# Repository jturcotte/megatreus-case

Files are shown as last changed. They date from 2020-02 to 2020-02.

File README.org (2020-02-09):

* Megatreus Keyboard

The Megatreus is a wireless hand-wired mechanical keyboard based
on the [[https://github.com/technomancy/atreus][Atreus keyboard]].
The layout is customized to use Ergodox keycaps, have a 2u spacebar
and an arrow key cluster.

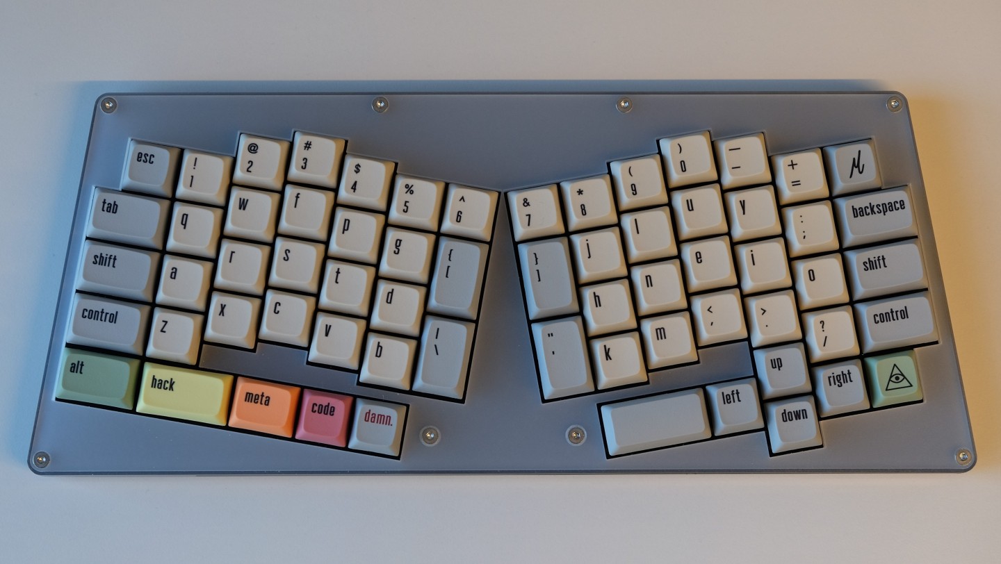
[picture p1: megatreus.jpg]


It uses an [[https://www.adafruit.com/product/4062][Adafruit Feather nRF52840 Express]]
microcontroller as its brain and is using the
[[https://github.com/jturcotte/megatreus-firmware][BlueMicro Firmware]]
to drive it.

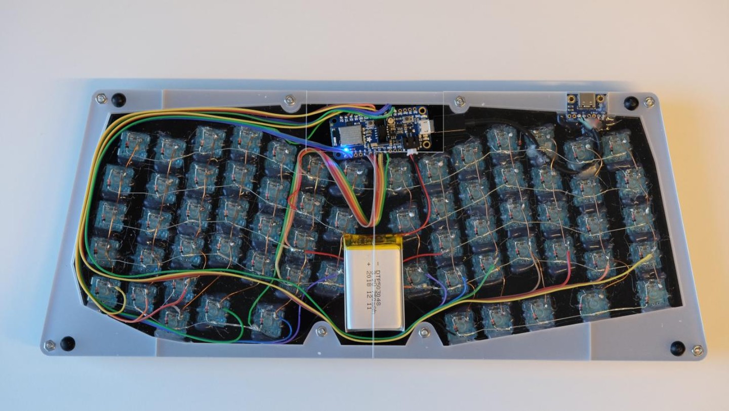
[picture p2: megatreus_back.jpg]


** License

Copyright © 2014-2018 Phil Hagelberg and contributors

Released under the [[https://www.gnu.org/licenses/gpl.html][GNU GPL version 3]]

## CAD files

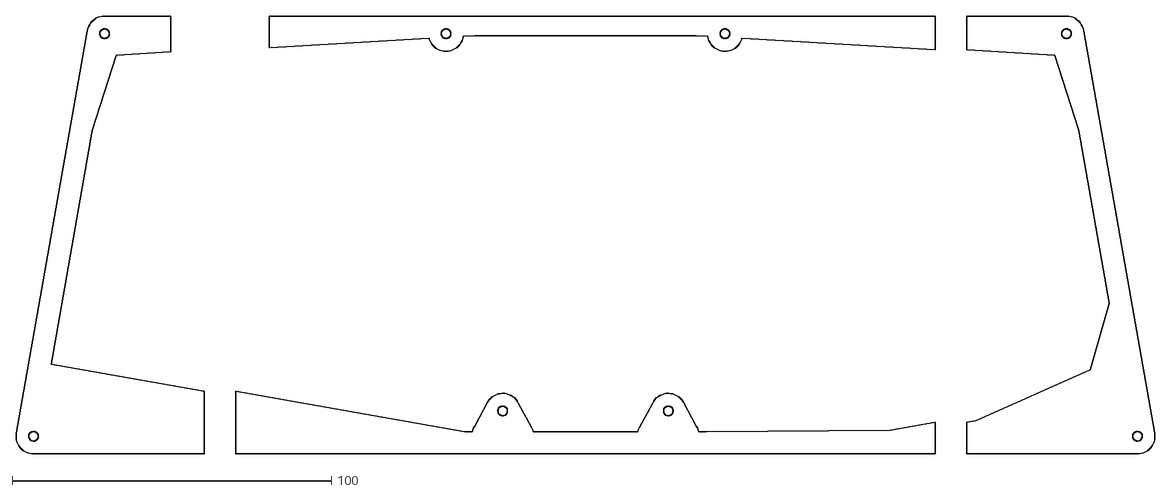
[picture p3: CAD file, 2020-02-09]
case/dxf/spacer.dxf
356.8 x 137.1

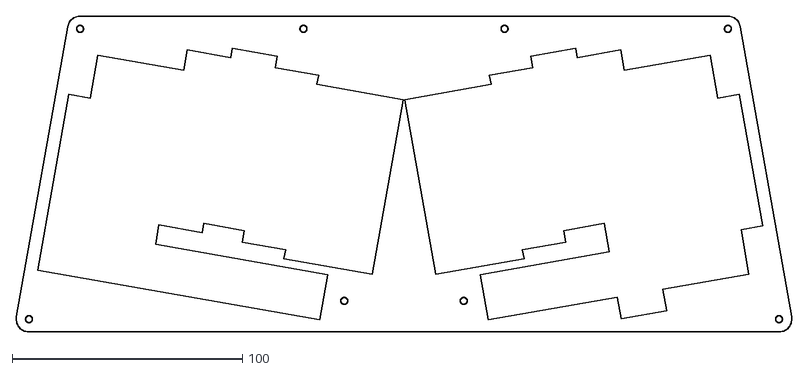
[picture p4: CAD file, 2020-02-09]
case/dxf/top_plate.dxf
336.8 x 137.1

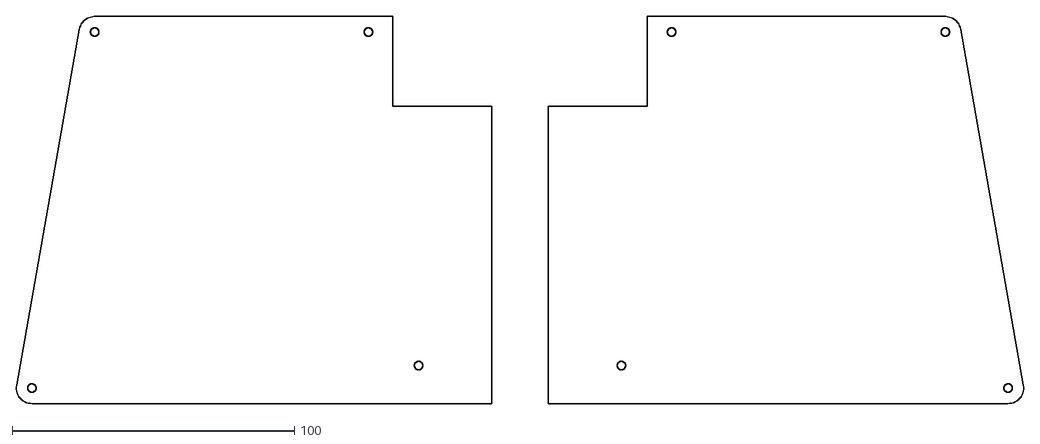
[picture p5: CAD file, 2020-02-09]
case/dxf/bottom_plate.dxf
356.8 x 137.1

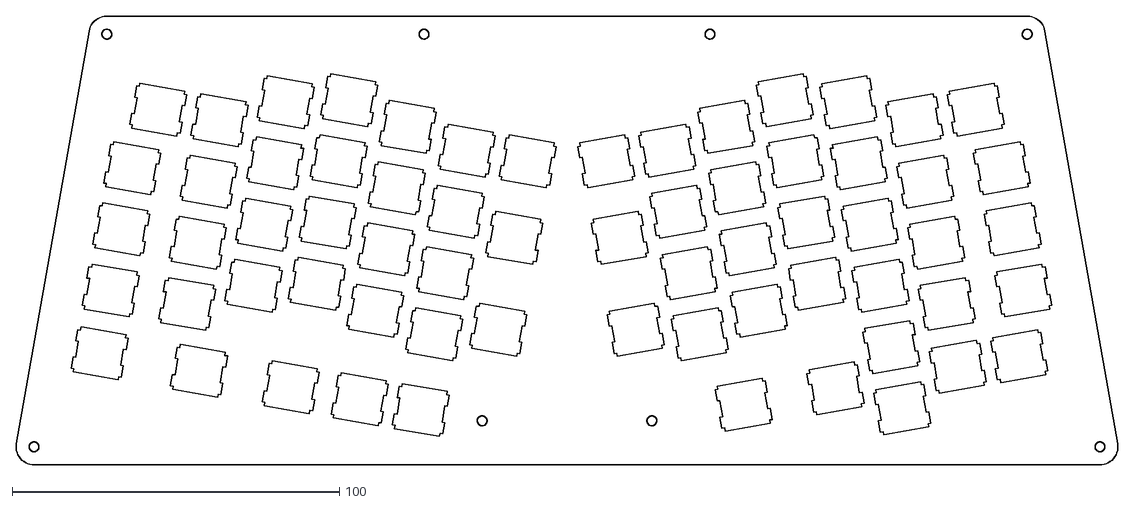
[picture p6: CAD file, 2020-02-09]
case/dxf/switch_plate.dxf
336.8 x 137.1

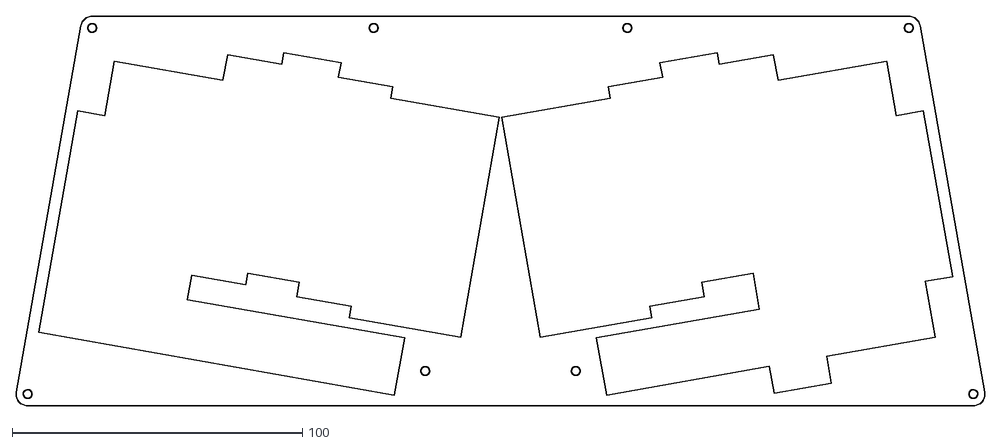
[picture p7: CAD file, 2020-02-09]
case/dxf/top_top_plate.dxf
333.8 x 134.1

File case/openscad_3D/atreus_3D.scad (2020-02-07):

// -*- mode: c -*-
/* All distances are in mm. */

/* set output quality */
$fn = 50;

/* Distance between key centers. */
column_spacing   = 19;
row_spacing      = column_spacing;

/* This number should exceed row_spacing and column_spacing. The
 default gives a 1mm = (20mm - 19mm) gap between keycaps and cuts in
 the top plate.*/
key_hole_size = 20;

/* rotation angle; the angle between the halves is twice this
   number */
angle = 10;

top_most_plate_bezel = 1.5;
/* The radius of screw holes. Holes will be slightly bigger due
   to the cut width. */
screw_hole_radius = 1.5;
/* Each screw hole is a hole in a "washer". How big these "washers"
   should be depends on the material used: this parameter and the
   `switch_hole_size` determine the spacer wall thickness. */
washer_radius     = screw_hole_radius * 2 + top_most_plate_bezel + 1;

/* Distance between halves. */
hand_separation        = 23;

/* The approximate size of switch holes. Used to determine how
   thick walls can be, i.e. how much room around each switch hole to
   leave. See spacer(). */
switch_hole_size = 14;

/* Sets whether the case should use notched holes. As far as I can
   tell these notches are not all that useful... */
use_notched_holes = true;

/* Number of rows and columns in the matrix. You need to update
   staggering_offsets if you change n_cols. */
n_rows = 5;
n_cols = 6;

/* Number of thumb keys (per hand), try 1 or 2. */
n_thumb_keys = 1;

/* The width of the USB cable hole in the spacer. */
cable_hole_width = 21;

/* Vertical column staggering offsets. The first element should
   be zero. */
staggering_offsets = [0, 4, 9, 5, -4, -4];
thumb_keys_y = staggering_offsets[3] - 0.5*column_spacing;

/* Whether or not to split the spacer into quarters. */
quarter_spacer = false;

/* Where the top/bottom split of a quartered spacer will be. */
cable_hole_offset = -120;

module rz(angle, center=undef) {
  /* Rotate children `angle` degrees around `center`. */
  translate(center) {
    rotate(angle) {
      translate(-center) {
        for (i=[0:$children-1])
          children(i);
      }
    }
  }
}

module switch_hole(position, notches=use_notched_holes) {
  /* Cherry MX switch hole with the center at `position`. Sizes come
     from the ErgoDox design. */
  hole_size    = 13.97;
  notch_width  = 3.5001;
  notch_offset = 4.2545;
  notch_depth  = 0.8128;
  translate(position) {
    union() {
        translate([0,0,-1])
      cube([hole_size, hole_size,50], center=true);
      if (notches == true) {
        translate([0, notch_offset,-1]) {
          cube([hole_size+2*notch_depth, notch_width,50], center=true);
        }
        translate([0, -notch_offset,-1]) {
          cube([hole_size+2*notch_depth, notch_width,50], center=true);
        }
      }
    }
  }
};

module keycap_hole(position, size=key_hole_size, ratio = [1, 1]) {
  /* Create a hole for a regular key. */
  translate(position) {
    w = size + column_spacing * (ratio[0] - 1);
    h = size + column_spacing * (ratio[1] - 1);
    cube([w, h, 50], center=true);
  }
}

module key(position, switch_holes, key_size=key_hole_size, ratio = [1, 1]) {
  if (switch_holes == true) {
    switch_hole(position);
  } else {
    keycap_hole(position, key_size, ratio);
  }
}

module regular_key (position, switch_holes, key_size=key_hole_size) {
  key(position, switch_holes, key_size);
}

module thumb_key (position, switch_holes, key_size=key_hole_size) {
  key(position, switch_holes, key_size, [1, 1.5]);
}

module space_bar (position, switch_holes, key_size=key_hole_size) {
  key(position, switch_holes, key_size, [2, 1]);
}

module outside_key (position, switch_holes, key_size=key_hole_size) {
  key(position, switch_holes, key_size, [1.5, 1]);
}

module column (bottom_position, switch_holes, key_size=key_hole_size, n_rows_adj=0) {
  /* Create a column of keys. */
  translate(bottom_position) {
    for (i = [0:(n_rows+n_rows_adj-1)]) {
      regular_key([0, i*column_spacing,-1], switch_holes, key_size);
    }
  }
}

module rotate_half() {
  /* Rotate the right half of the keys around the top left corner of
     the thumb key. Assumes that the thumb key is a 1x1.5 key and that
     it is shifted 0.5*column_spacing up relative to the nearest column. */
  rotation_y_offset = 1.75 * column_spacing;
  for (i=[0:$children-1]) {
    rz(angle, [hand_separation, rotation_y_offset]) {
      children(i);
    }
  }
}

module add_hand_separation() {
  /* Shift everything right to get desired hand separation. */
  for (i=[0:$children-1]) {
    translate([0.5*hand_separation, /* we get back the full separation
                                       because of mirroring */
               0]) children(i);
  }
}

module right_half (switch_holes=true, key_size=key_hole_size, really_right_half=true) {
  /* Create switch holes or key holes for the right half of the
     keyboard. Different key_sizes are used in top_plate() and
     spacer(). */
  x_offset = 0.5 * row_spacing;
  y_offset = 0.5 * column_spacing;
  thumb_key_offset = y_offset + 1.25 * column_spacing + staggering_offsets[0];
  arrow_key_offset = y_offset;

  rotate_half() {
    add_hand_separation() {
      // 2x 1.5u keys
      for (j=[0:1]) {
        thumb_key([x_offset, thumb_key_offset + j * 1.5 * column_spacing,-1], switch_holes, key_size);
      }
      // 1u keys above for the inside
      for (j=[0:0]) {
        regular_key([x_offset, thumb_key_offset + j * 1 * column_spacing + 2.75 * column_spacing,-1], switch_holes, key_size);
      }


      if (really_right_half) {
        // Space bar
        space_bar([x_offset + (0.5+n_thumb_keys)*row_spacing, y_offset + thumb_keys_y,-1], switch_holes, key_size);
        // Up arrow
        regular_key([x_offset + (3+n_thumb_keys)*row_spacing, y_offset + staggering_offsets[3],-1], switch_holes, key_size);
        // Down arrow
        regular_key([x_offset + (3+n_thumb_keys)*row_spacing, y_offset + staggering_offsets[3] - column_spacing,-1], switch_holes, key_size);
        // Left arrow
        regular_key([x_offset + (2+n_thumb_keys)*row_spacing, y_offset + staggering_offsets[3] - 0.5*column_spacing,-1], switch_holes, key_size);
        // Right arrow
        regular_key([x_offset + (4+n_thumb_keys)*row_spacing, y_offset + staggering_offsets[3] - 0.5*column_spacing,-1], switch_holes, key_size);
        // AltGr/Fn
        regular_key([x_offset + (5+n_thumb_keys)*row_spacing, y_offset + staggering_offsets[3] - 0.5*column_spacing,-1], switch_holes, key_size);

        // Normal keys
        // One less key, and offset up by one key.
        for (j=[0:(n_cols-2)]) {
          column([x_offset + (j+n_thumb_keys)*row_spacing, y_offset + column_spacing + staggering_offsets[j]], switch_holes, key_size, -1);
        }
      } else {
        // Normal keys
        // One less key, and offset up by one key.
        for (j=[0:4]) {
          column([x_offset + (j+n_thumb_keys)*row_spacing, y_offset + column_spacing + staggering_offsets[j]], switch_holes, key_size, -1);
        }
        // Move the left out keys a bit lower for easier thumb access
        regular_key([x_offset + (0+n_thumb_keys)*row_spacing, y_offset + thumb_keys_y,-1], switch_holes, key_size);
        regular_key([x_offset + (1+n_thumb_keys)*row_spacing, y_offset + thumb_keys_y,-1], switch_holes, key_size);
        // 1.25u and 1.75u keys in the middle
        key([x_offset + (2+n_thumb_keys+0.125)*row_spacing, y_offset + thumb_keys_y,-1], switch_holes, key_size, [1.25, 1]);
        key([x_offset + (4+n_thumb_keys-0.375)*row_spacing, y_offset + thumb_keys_y,-1], switch_holes, key_size, [1.75, 1]);

        // Outside column
        // Bottom 1.5u
        outside_key([
            x_offset + 0.25*row_spacing + (n_cols-1+n_thumb_keys)*row_spacing,
            y_offset + thumb_keys_y,-1
          ], switch_holes, key_size);
      }

      // Outside column
      // Middle 1.5u
      for (i = [1:(n_rows-2)]) {
        outside_key([
            x_offset + 0.25*row_spacing + (n_cols-1+n_thumb_keys)*row_spacing,
            y_offset + staggering_offsets[n_cols - 1] + i*column_spacing,-1
          ], switch_holes, key_size);
      }
      // Top 1u
      regular_key([
          x_offset + (n_cols-1+n_thumb_keys)*row_spacing,
          y_offset + staggering_offsets[n_cols - 1] + (n_rows-1)*column_spacing,-1
        ], switch_holes, key_size);
    }
  }
}

module screw_hole(radius, position) {
  /* Create a screw hole of radius `radius` at a location `position`. */
  translate(position) {
    cylinder(r1=radius,r2=radius,h=3);
  }
}

function unrotate_align_right(ref_point, new_x) =
  [new_x, ref_point[1] + (new_x - ref_point[0]) * tan(-angle)];

function unrotate_align_left(ref_point, new_x) =
  [new_x, ref_point[1] - (new_x - ref_point[0]) * tan(angle)];
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

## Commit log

2019-07-16 tweaking random stuff
    [atreus_3D.scad]
2019-07-16 Have something that looks alright
    [atreus_3D.scad]
2019-07-17 tweaks, not really pretty
    [atreus_3D.scad]
2019-09-07 Starting to look good
    [atreus_3D.scad]
2019-09-16 Remove arrow keys and put 2x 1.5 in the middle
    [atreus_3D.scad]
2019-10-31 Remove middle key to put the feather there
    [atreus_3D.scad]
2019-11-01 Add arrow keys, doesn't look too bad
    [atreus_3D.scad]
2019-11-02 Make top edge corner key 1u
    [atreus_3D.scad]
2019-11-02 Screw holes adjustments
    [atreus_3D.scad]
2019-11-10 Changing the layout to align the bottom row
    [atreus_3D.scad]
2019-11-14 Adjust the thumb keys
    [atreus_3D.scad]
2019-11-14 Fix keycap hole edge scaling
    [atreus_3D.scad]
2019-11-14 Set the 1.75 and 1.25 thumb row keys
    [atreus_3D.scad]
2019-11-17 Adjustments to the staggering and slot for the microcontroller
    [atreus_3D.scad]
2019-11-19 Try to align the front screw holes
    [atreus_3D.scad]
2019-12-07 Seems to work
    [atreus_3D.scad]
2019-12-14 Also use the unrotate for the back center hole, and clean up
    [atreus_3D.scad]
2019-12-14 Fix the edge gap
    [atreus_3D.scad]
2019-12-15 Add some space for the mc
    [atreus_3D.scad]
2020-01-13 Size adjustments after the first prototype
    [atreus_3D.scad]
2020-01-13 Adjust the breakout board hole and add some space for the bluefruit
    [atreus_3D.scad]
2020-01-13 Change the spacer cutting to move over the cable hole
    [atreus_3D.scad]
2020-01-15 Move the front center holes in the empty key spot
    f
    [atreus_3D.scad]
2020-01-15 Split the bottom plate in 2
    [atreus_3D.scad]
2020-01-15 Try again to use smaller holes
    [atreus_3D.scad]
2020-01-15 Add a hole on the back plate to expose the micro-controller
    [atreus_3D.scad]
2020-01-15 Move cable hole to the other side and leave some space for wiring
    [atreus_3D.scad]
2020-01-15 Comment out fake screw heads
    [atreus_3D.scad]
2020-02-07 Fix the cable hole position vs the spacers' cutting
    [atreus_3D.scad]
2020-02-09 Remove files not applying to the fork
    [atreus.kicad_pcb, atreus.stl, atreus_bottom.stl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]
2020-02-09 Add generated DXF files
    [bottom_plate.dxf, spacer.dxf, switch_plate.dxf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]
